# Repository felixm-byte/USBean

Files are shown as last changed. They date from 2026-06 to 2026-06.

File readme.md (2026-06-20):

# USBean

A bean-shaped USB hub with a display and RP2040 microcontroller, to provide some friendly motivation, tips, or simply the time or other ambient data, while helping you to organise your desk. 

I made this since I've always struggled with organising cables for peripherals on my desk, and also thought having a simple second display is really useful for displaying data, like a timer or friendly motivational messages, without interrupting the important tasks on the main display. It's a bean because beans are both our friends and very useful to us, just like this will be. 

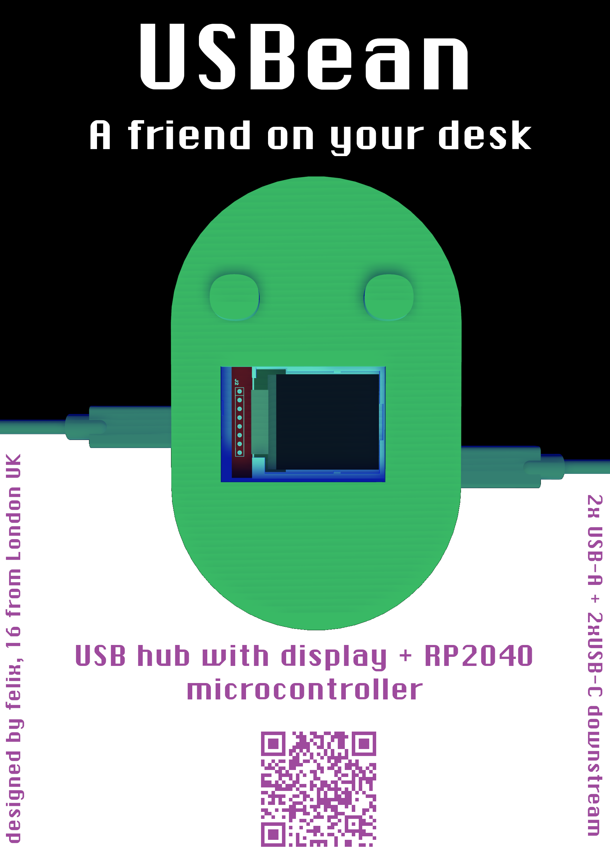
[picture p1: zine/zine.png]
zine/poster demonstrating key features, with 3D render

## Features

- Connect to your host device using USB-C
- 3x USB ports for secondary devices (2x USB-A, 1x USB-C)
- USB 2.0 data speeds
- Protection from electro-static discharge to keep devices safe
- Programmable RP2040 microcontroller (16MB flash) linked to your device
- Simple and light 3D-printed case - 2-part assembly with no screws
- 1.8in colour display for text and graphics

## Assembly

Assemble the PCB or use a PCBA service like JLCPCB (recommended due to small part sizes especially for RP2040).

Insert the display module into the PCB's header, ensuring the display is pointing inwards so sits above the PCB, instead of jutting out from the PCB. If it is aligned wrong, it will not function as expected and could break.

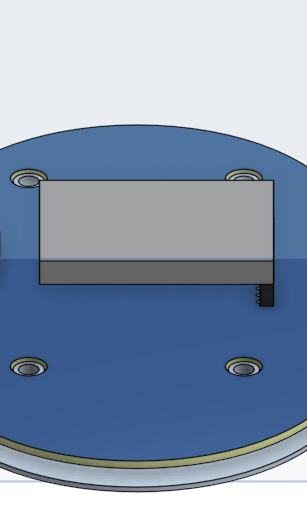
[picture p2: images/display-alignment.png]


Use the bottom piece (image below) as the base, and align the mounting holes with the bottom piece. It only fits in one orientation, so make sure the PCB is not jutting out of the edges of the case.

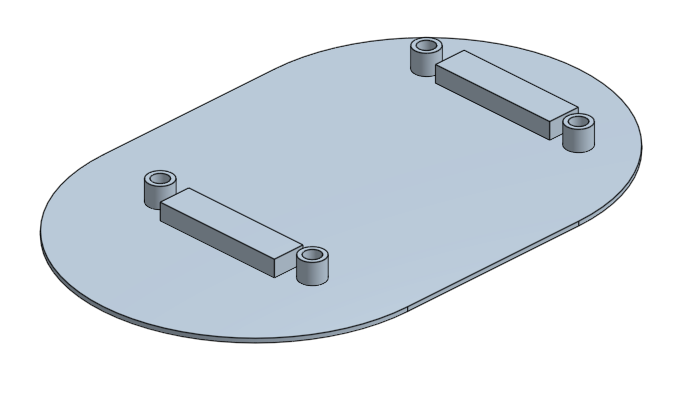
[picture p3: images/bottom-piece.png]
bottom piece


Correct positioning onto bottom piece:

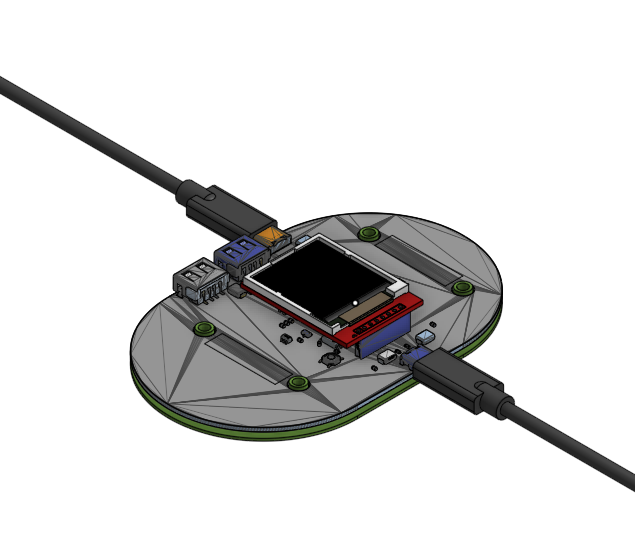
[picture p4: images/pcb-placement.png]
pcb placement


Flash MicroPython onto the Pi Pico by plugging your computer into the USB port marked as 'main USB port' on the PCB. [This guide](https://www.digikey.co.uk/en/maker/projects/raspberry-pi-pico-and-rp2040-micropython-part-1-blink/58b3c31ac93649849b58824caa00529c) is helpful in explaining how to flash it - you can use the BOOTSEL button on this PCB just as you do the BOOTSEL button on the Pi Pico.

Once the software is configured, lower the remaining 3D printed piece into the holes through the PCB, ensuring it is aligned so that it does not jut out of the edge of the case either.

Plug in your peripherals using the USB ports on the other side, and you're good to go!

Completed build:
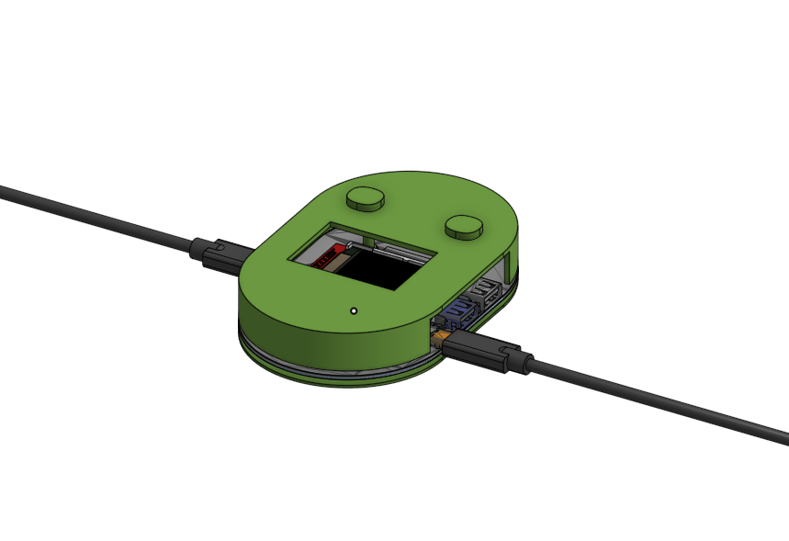
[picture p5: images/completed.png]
completed


## Software

Note: the code for this has not been fully tested on the hardware, so unexpected behaviour is possible, but this does not affect the USB hub functionality, only the smart display.

Use the MicroPython tools to flash the code in software/microcontroller onto the RP2040 chip (once micropython has been flashed onto the chip, see 'Assembly'). This [guide](https://pip-assets.raspberrypi.com/categories/610-raspberry-pi-pico/documents/RP-008355-DS-1-raspberry-pi-pico-python-sdk.pdf) explains how to flash it and is also generally useful for understanding how to use the microcontroller with Python. Run the pi-messenger.py script on your computer connected to the USBean via USB (connected to the main USB port, on the side with only one usb-c port), and, all going well, it should establish communications and enable you to use functions like the timer, or write your own!!

## Design decisions

The case doesn't fully protect the PCB from the outside to provide extra clearance so that weird devices can still fit into the USB ports, and also to expose the PCB to the user because I think it looks cool. The mechanism for seperating the parts of the case means it could fall apart if the case is aggressively shaken in the vertical direction, but since it is meant as a desk-top device, I think this is okay, and the trade-off means it can have fewer parts, making it cheaper, and it is very easy to assemble and disassemble, so overall I think it is worthwhile.

## Reviewing or editing notes

- Access the 3D assembly files on [OnShape](https://cad.onshape.com/documents/80b4cd38b52a4e1c99c47e9f/w/17e039e92c67e43612d5fe93/e/d8b3fe0a87e4e6a6eee19e1b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)

## Design details

Schematic:

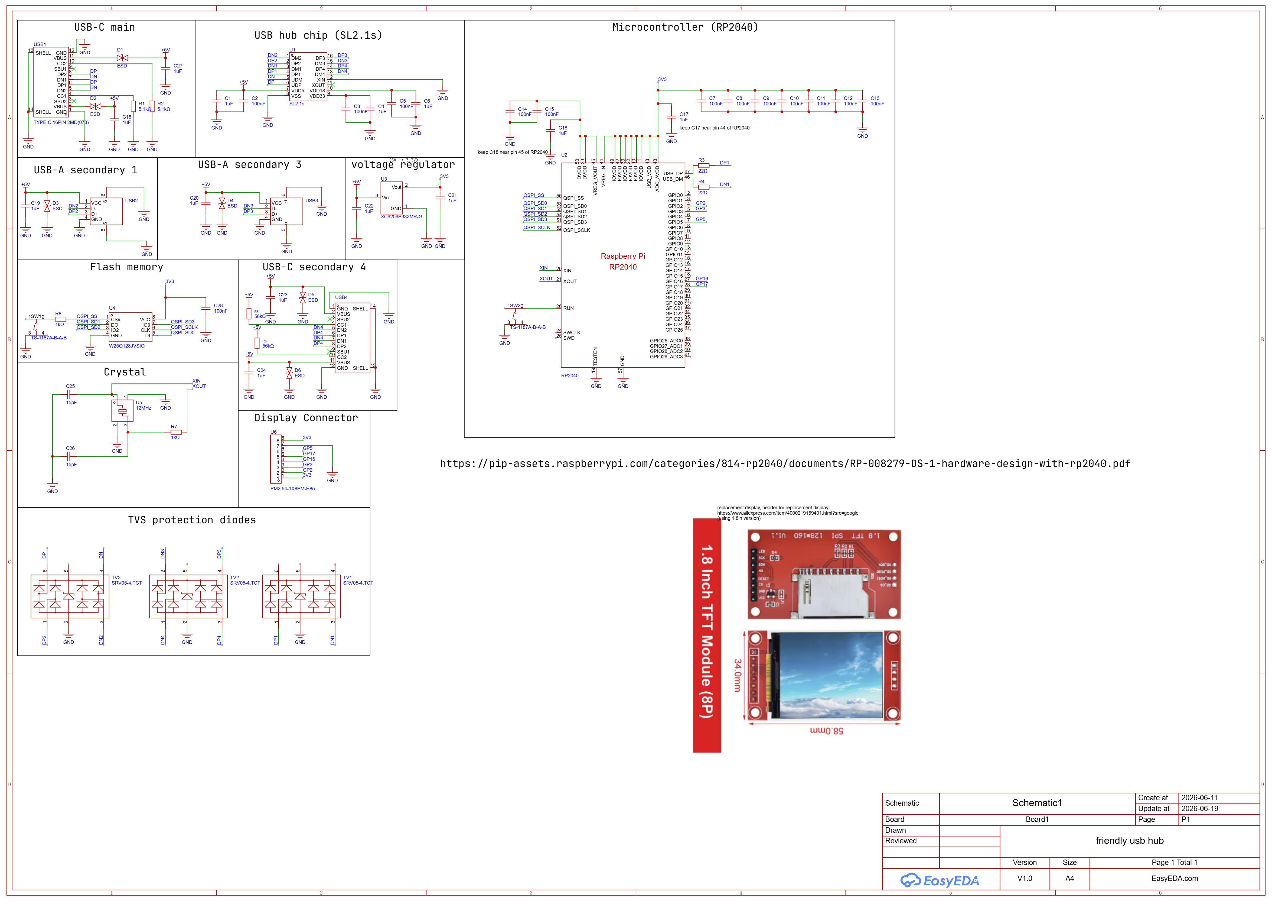
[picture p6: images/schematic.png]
schematic


PCB:

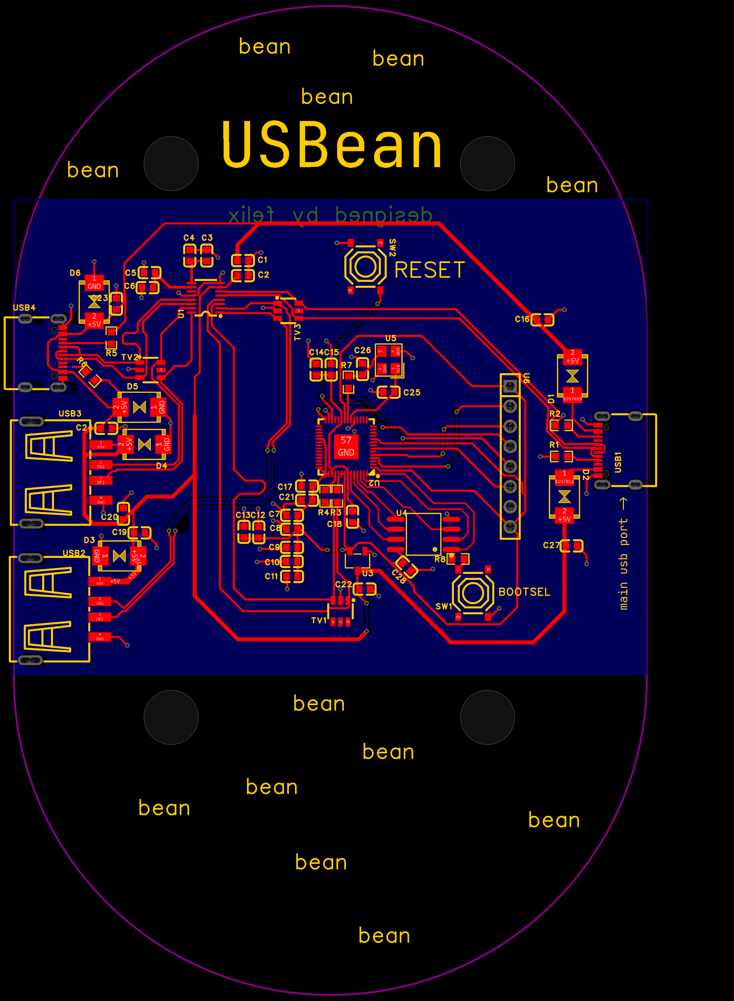
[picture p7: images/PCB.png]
pcb


## Acknowledgements

 - [Hack Club USB hub tutorial](https://fallout.hackclub.com/docs/guided-projects/usb-hub)
 - [RP2040 design reference](https://pip-assets.raspberrypi.com/categories/814-rp2040/documents/RP-008279-DS-1-hardware-design-with-rp2040.pdf)
 - [ST7735 python lib](https://github.com/boochow/MicroPython-ST7735)

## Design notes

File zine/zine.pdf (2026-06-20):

# USBean

## A friend on your desk

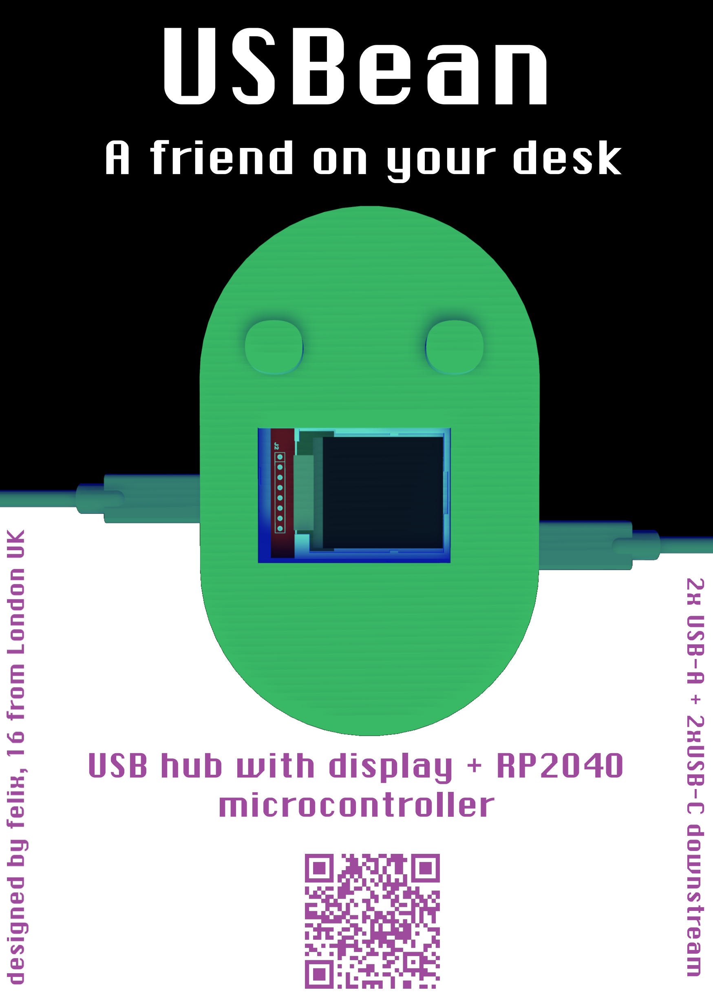
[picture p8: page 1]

USB hub with display + RP2040 microcontroller

2x USB-A + 2xUSB-C downstream

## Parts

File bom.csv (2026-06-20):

USBean Parts
Designator | Mrf# | Mfr. | Order Qty. | Unit Price(USD) | Ext.Price(USD) | LCSC# | Package | Min | Mult | SPQ | Availability | Stock Status | Description | Product Link
SW1,SW2 | TS-1187A-B-A-B | XKB Connection | 20 | 0.0198 | 0.4 | C318884 | SMD-4P,5.1x5.1mm | 20 | 20 | 4000 | 1532800 | In Stock | Tactile Switch SPST 160gf 1.5mm 5.1mm x 5.1mm Surface Mount | https://www.lcsc.com/product-detail/C318884.html
U1 | SL2.1s | CoreChips | 5 | 0.2534 | 1.27 | C2684433 | SSOP-16 | 5 | 5 | 7500 | 19855 | In Stock | Hub USB 2.0 SSOP-16 Interface Controllers RoHS | https://www.lcsc.com/product-detail/C2684433.html
U2 | RP2040 | Raspberry Pi | 1 | 0.9930 | 0.99 | C2040 | LQFN-56(7x7) | 1 | 1 | 3400 | 45523 | In Stock | 133MHz 30 LQFN-56(7x7) Microcontrollers RoHS | https://www.lcsc.com/product-detail/C2040.html
U3 | XC6206P332MR-G | TOREX | 5 | 0.1186 | 0.59 | C5446 | SOT-23-3L | 5 | 5 | 3000 | 362600 | In Stock | 3.3V Positive Fixed SOT-23-3L Voltage Regulators - Linear, Low Drop Out (LDO) Regulators RoHS | https://www.lcsc.com/product-detail/C5446.html
U4 | W25Q128JVSIQ | Winbond | 1 | 2.4553 | 2.46 | C97521 | SOIC-8-208mil | 1 | 1 | 2000 | 39006 | In Stock | 2.7V~3.6V 128Mbit 133MHz SPI SOIC-8-208mil Memory (ICs) RoHS | https://www.lcsc.com/product-detail/C97521.html
U5 | ABM8-272-T3 | ABRACON | 5 | 0.2956 | 1.48 | C20625731 | SMD3225-4P | 5 | 5 | 3000 | 15140 | In Stock | �30ppm 10pF �30ppm SMD3225-4P Crystals RoHS | https://www.lcsc.com/product-detail/C20625731.html
U6 | PM2.54-1X8PM-H85 | JXTCONN | 5 | 0.1002 | 0.5 | C42431840 | Through Hole,P=2.54mm | 5 | 5 | 400 | 12860 | In Stock | 3A 8P Through Hole -40?~+105? 8.5mm 1x8P 2.54mm Top 1 Square Hole Through Hole,P=2.54mm Headers, Receptacles, Female Sockets RoHS | https://www.lcsc.com/product-detail/C42431840.html
USB2,USB3 | 10.0 QHHTZB6.3 | SHOU HAN | 10 | 0.0636 | 0.64 | C668591 | SMD | 10 | 10 | 100 | 33150 | In Stock | USB-A (USB TYPE-A) Receptacle Connector 4 Position Surface Mount, Right Angle | https://www.lcsc.com/product-detail/C668591.html
D1,D2,D3,D4,D5,D6 | P6SMB6.8CA/TR13 | Brightking | 10 | 0.0533 | 0.53 | C78395 | SMB(DO-214AA) | 10 | 10 | 3000 | 236350 | In Stock | 10.5VC Clamp 58.1A Ipp TVS DIODE SMB(DO-214AA) | https://www.lcsc.com/product-detail/C78395.html
C1,C4,C6,C16,C17,C18,C19,C20,C21,C22,C23,C24,C27 | CL10A105KB8NNNC | Samsung Electro-Mechanics | 50 | 0.0131 | 0.66 | C15849 | 0603 | 50 | 50 | 4000 | 0 | Backordered | 1uF �10% 50V Ceramic Capacitor X5R 0603 | https://www.lcsc.com/product-detail/C15849.html
C2,C3,C5,C7,C8,C9,C10,C11,C12,C13,C14,C15,C28 | CC0603KRX7R9BB104 | YAGEO | 100 | 0.0172 | 1.72 | C14663 | 0603 | 100 | 100 | 4000 | 0 | Backordered | 100nF �10% 50V Ceramic Capacitor X7R 0603 | https://www.lcsc.com/product-detail/C14663.html
C25,C26 | CL10C150JB8NNNC | Samsung Electro-Mechanics | 100 | 0.0092 | 0.92 | C1644 | 0603 | 100 | 100 | 4000 | 27000 | In Stock | 15pF �5% 50V Ceramic Capacitor C0G 0603 | https://www.lcsc.com/product-detail/C1644.html
R1,R2 | 0603WAF5101T5E | UNI-ROYAL | 100 | 0.0019 | 0.19 | C23186 | 0603 | 100 | 100 | 5000 | 0 | Backordered | 5.1k? �1% 100mW 0603 Thick Film Resistor | https://www.lcsc.com/product-detail/C23186.html
R5,R6 | 0603WAF5602T5E | UNI-ROYAL | 100 | 0.0020 | 0.2 | C23206 | 0603 | 100 | 100 | 5000 | 0 | Backordered | 56k? �1% 100mW 0603 Thick Film Resistor | https://www.lcsc.com/product-detail/C23206.html
R7,R8 | 0603WAF1001T5E | UNI-ROYAL | 100 | 0.0018 | 0.18 | C21190 | 0603 | 100 | 100 | 5000 | 0 | Backordered | 1k? �1% 100mW 0603 Thick Film Resistor | https://www.lcsc.com/product-detail/C21190.html
USB1,USB4 | TYPE-C 16PIN 2MD(073) | SHOU HAN | 20 | 0.0707 | 1.41 | C2765186 | SMD | 20 | 20 | 1000 | 1331380 | In Stock | USB-C (USB TYPE-C) Receptacle Connector 16 Position Surface Mount, Right Angle | https://www.lcsc.com/product-detail/C2765186.html
R3,R4 | 0603WAF220JT5E | UNI-ROYAL | 100 | 0.0017 | 0.17 | C23345 | 0603 | 100 | 100 | 5000 | 0 | Backordered | 22? �1% 100mW 0603 Thick Film Resistor | https://www.lcsc.com/product-detail/C23345.html
TV1,TV2,TV3 | SRV05-4.TCT | SEMTECH | 5 | 0.1506 | 0.75 | C13612 | SOT-23-6L | 5 | 5 | 3000 | 81270 | In Stock | 17.5VC Clamp 12A@8/20us Ipp TVS DIODE SOT-23-6L | https://www.lcsc.com/product-detail/C13612.html
LCSC parts sub-total: |  |  |  |  | 15.06
Display | 1.8 TFT NO TOUCH | TZT teng | 1 | 2.12 | 2.12 |  | 8-pin TFT display | 1 | 1 |  |  | In stock |  | https://www.aliexpress.com/item/4000219159401.html
3D printed case |  | JLC3DP (or print at home ?? for free) | 1 |  | 3.09 |  |  |  |  |  |  | N/A |  | https://jlc3dp.com/3d-printing-quote
Total |  |  | 2 |  | 20.27

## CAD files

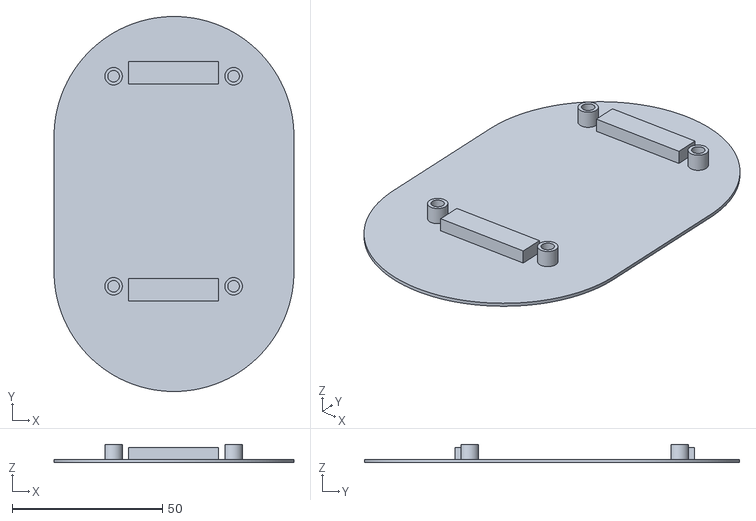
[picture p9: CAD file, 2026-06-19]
hardware/case-part.stl
80.0 x 125.0 x 6.00

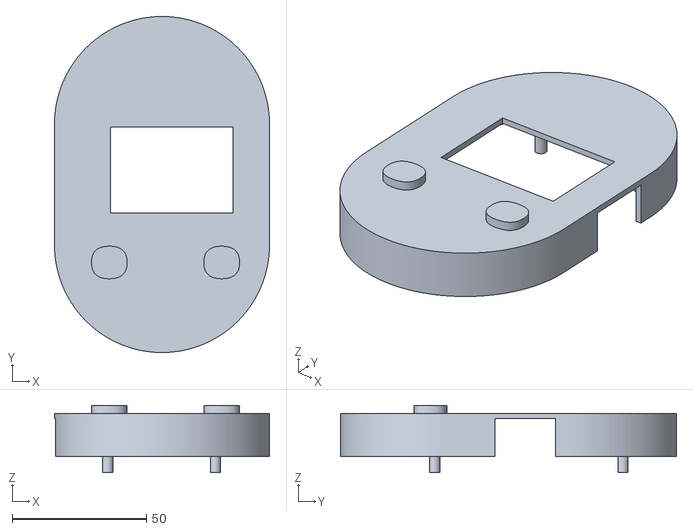
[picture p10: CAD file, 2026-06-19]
hardware/case-part-2.stl
80.0 x 125.0 x 25.1

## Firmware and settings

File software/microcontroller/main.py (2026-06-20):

from ST7735 import TFT
from sysfont import sysfont
from machine import SPI,Pin
import sys
import select
import machine

# Setup onboard LED
led = machine.Pin(25, machine.Pin.OUT)
poll_obj = select.poll()
poll_obj.register(sys.stdin, select.POLLIN)
spi = SPI(2, baudrate=20000000, polarity=0, phase=0, sck=Pin(2), mosi=Pin(3), miso=Pin(-1), cs=Pin(5))
tft=TFT(spi,2,3)
tft.initr()
tft.rgb(True)


while True:
    # Check if data is waiting in the USB serial buffer
    if poll_obj.poll(0):
        # Read the incoming message and remove whitespace
        message = sys.stdin.readline().strip().lower()
        
        if message:
            print("Recieved:")
            print(message)
            tft.fill(TFT.BLACK)
            tft.text((0, 30), {message}, TFT.RED, sysfont, 1, nowrap=False)

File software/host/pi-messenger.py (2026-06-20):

import serial
import time

def send_msg(content, port, baud_rate = 115200, is_temporary=False, display_time=0):
# Open connection
    try:
        ser = serial.Serial(port, baud_rate, timeout=1)
        time.sleep(2) # Wait for the board to reset/initialize
        # Send message to RP2040
        ser.write(content.encode('utf-8'))
        print(f"Sent: {content.strip()}")
        if is_temporary:
            time.sleep(display_time)
            ser.write("".encode('utf-8'))         
    except Exception as e:
        print(f"Error: {e}")
    finally:
        ser.close()

def pi_active_at(port, baud_rate = 115200):
    try: 
        ser = serial.Serial(port, baud_rate, timeout=1)
        print(f"Success: connection established with {ser}")
    except Exception as e:
        print(f"Failure: connection failed with exception {e}")
        return False
    
def time_in_words(secs):
    text = ""
    hrs = 0
    mins = 0
    if secs >= 3600:
        hrs = secs // 3600
        secs -= hrs*3600
    if secs >= 60:
        mins = secs // 60
        secs -= mins*60
    
    if hrs >= 1:
        text = f"{hrs}:{'0' if len(str(mins)) != 2 else ''}{mins}:{'0' if len(str(secs)) != 2 else ''}{secs}"
    elif mins >=1:
        text = f"{mins}:{'0' if len(str(secs)) != 2 else ''}{secs}"
    else:
        text = f"{secs} seconds"
    return text
#def start_timer(duration): #Duration in seconds

def timer(time, port, baud_rate = 115200):
    if pi_active_at(port, baud_rate):
        send_msg(f"{time_in_words(time)} timer, starting soon :>", port, baud_rate)
        time.sleep(7)
        n = time
        while n >= 0:
            n-= 1
            text = time_in_words(time)
            send_msg(f"{time_in_words(time)} remaining", port, baud_rate)
            time.sleep(1)
        send_msg("Time's up!!", port, baud_rate, is_temporary=True, display_time=15)
    else:
        return False
        

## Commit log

2026-06-19 New product ver, README
    [bom.csv, case-part-2.stl, case-part.stl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]
2026-06-20 Designing zine, code, readme
    [bom.csv]
